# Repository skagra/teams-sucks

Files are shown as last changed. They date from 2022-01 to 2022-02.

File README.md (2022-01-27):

# Teams Sucks

I often find myself on mute during *M$ Teams* meetings and struggle to find the relevant window to be able to unmute.

This project solves the problem by providing an external physical device with buttons to bring *Teams* windows to the front/cycle them, to toggle mute and to toggle the camera.

The project consists of:

* Hardware
   * Based around a Microcontroller, with status LCD and sound signals.   
   * Connectivity to the PC running *Teams* via Bluetooth or USB.
   * Powerable via a battery or USB.
   * C++ software uploaded to the Microcontroller to control the function of the device and to communicate with the PC.
* Protocol
   * A simple network protocol between the hardware device and the PC.
* PC software
   * A .Net application which communicates with the hardware device, taking instructions and driving *Teams* appropriately.

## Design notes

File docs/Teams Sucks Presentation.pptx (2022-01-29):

## YOU’RE

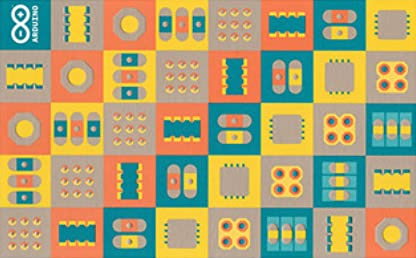
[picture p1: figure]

ON MUTE!

A Device to Control M$ Teams

## Components of the Solution

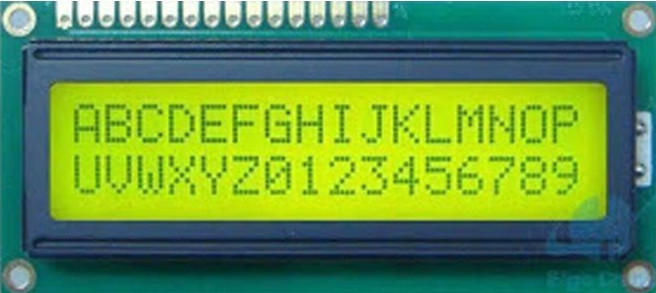
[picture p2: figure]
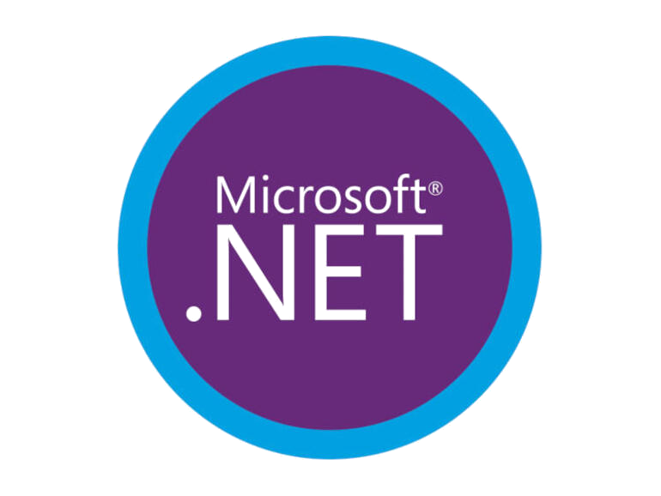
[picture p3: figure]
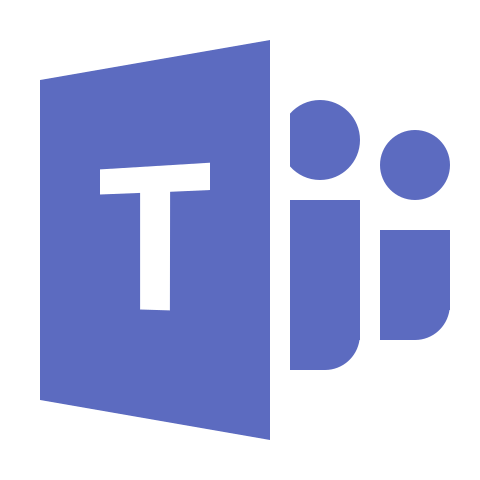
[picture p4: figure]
Microsoft Teams (int. sub-page) | Wired Relations ...

101010010101

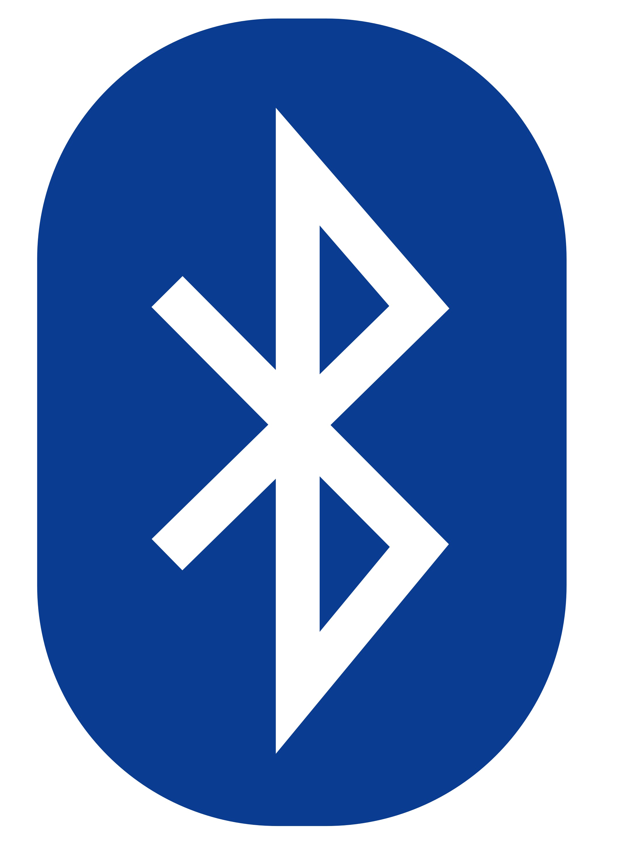
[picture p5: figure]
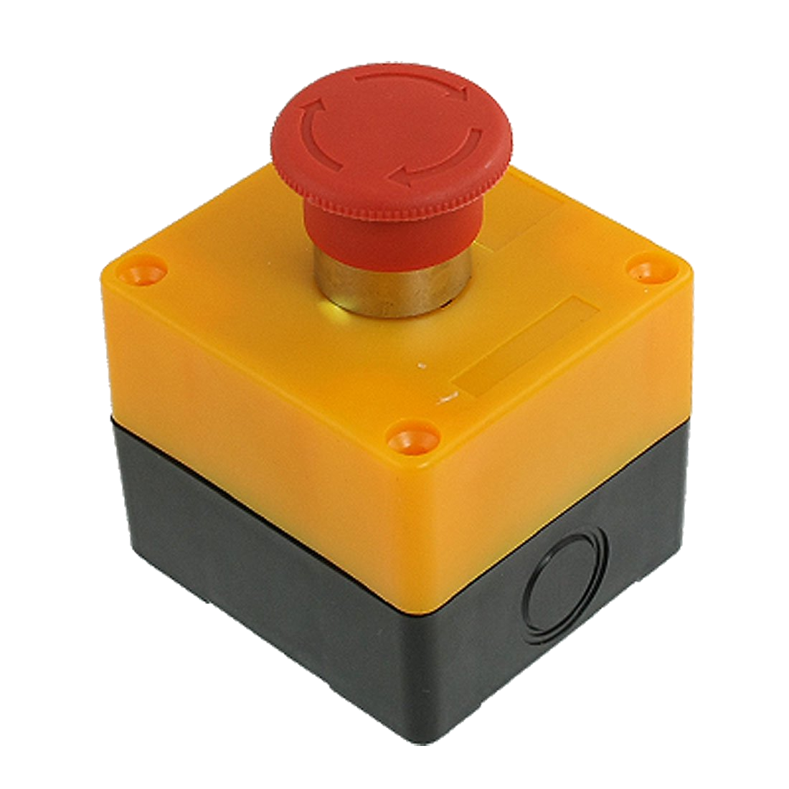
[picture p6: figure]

Cycle
Windows

Toggle
Mute

Toggle
Camera

External

Wireless

PC software to

hardware

protocol

control teams

## Hardware - Microcontroller

C++

Arduino Nano

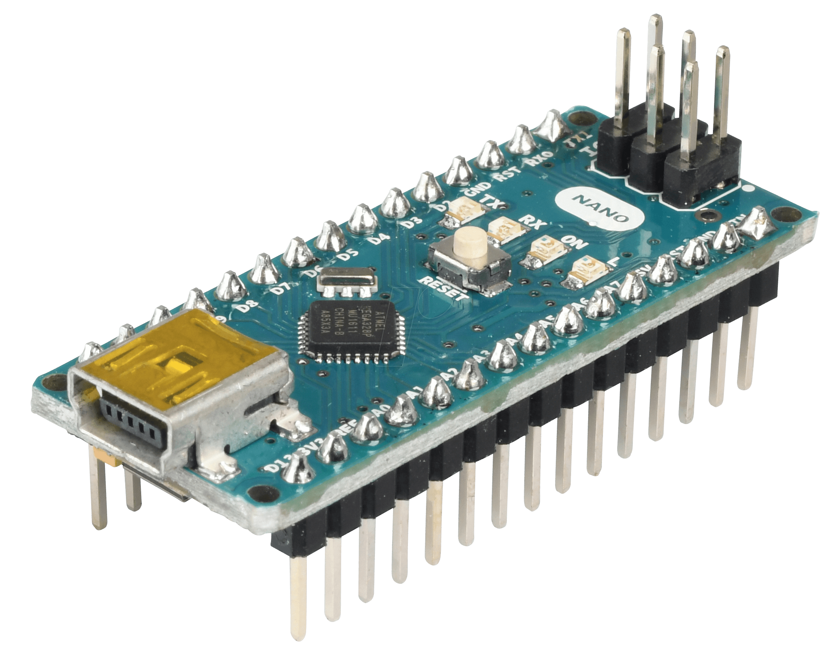
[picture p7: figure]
ARDUINO NANO: Arduino Nano V3, ATmega 328, Mini USB at ...

- ATmega328 Microcontroller
- 32K Flash
- 2K DRAM
- 14 digital I/O pins
- 8 Analogue I/O pins
- 40 mA per pin

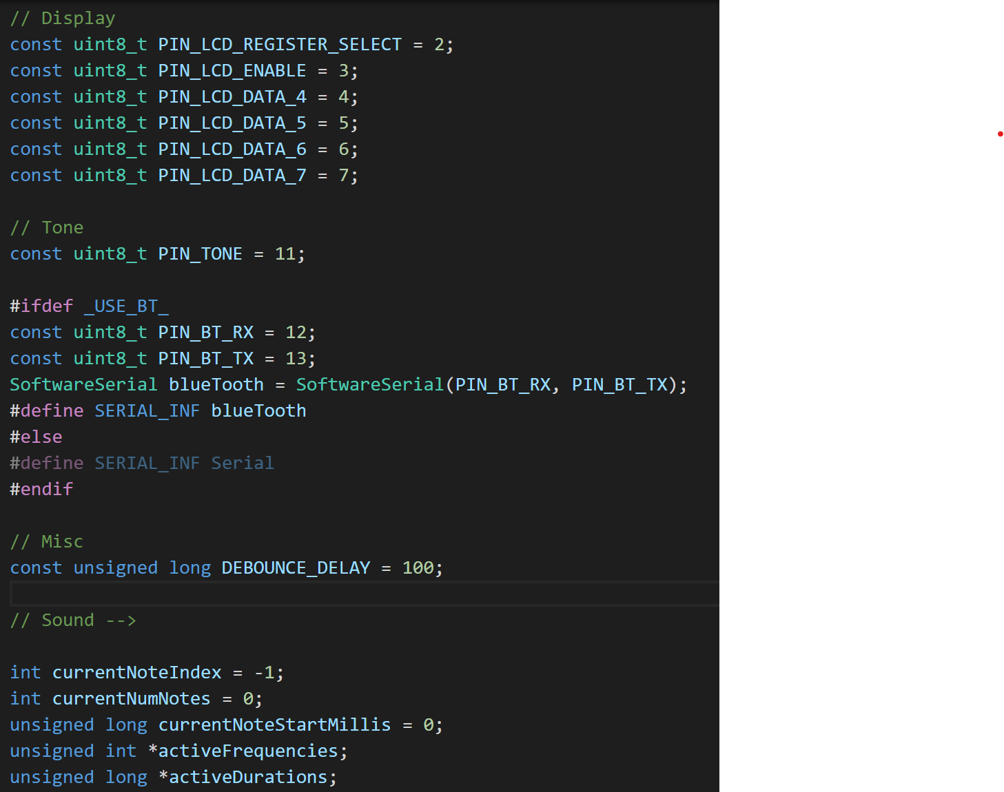
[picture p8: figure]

Compile

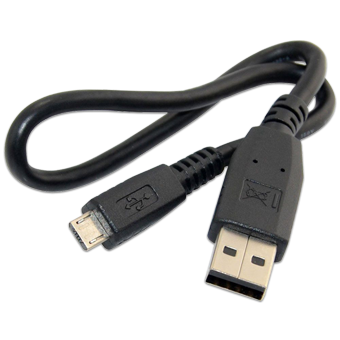
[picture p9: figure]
30cm Short Genuine BlackBerry Micro USB Data Sync Charger ...

Upload

## Hardware - Schematic

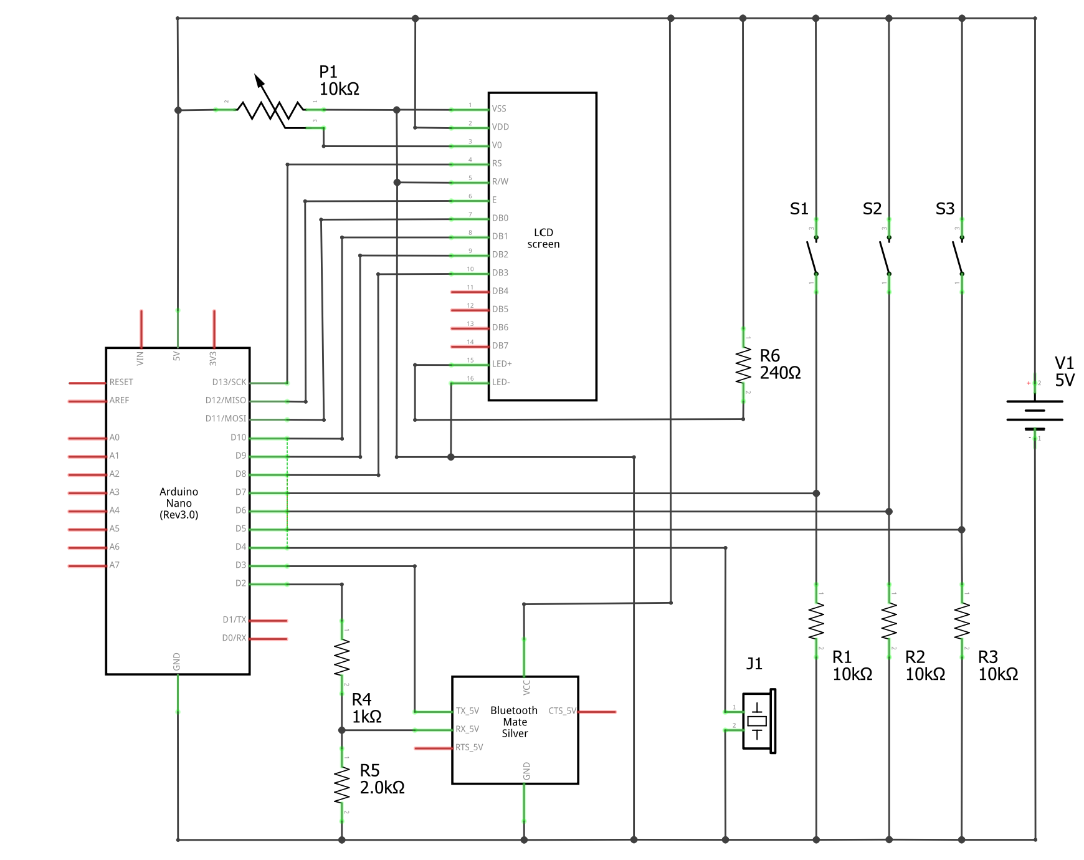
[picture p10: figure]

P1 – LCD contrast

LCD

S1 – Cycle
S2 – Mute
S3 - Camera

R6 - Current limiting resistor for LED backlight

Arduino Nano

Bluetooth/ HC-05

R1, R2, R3 - Pulldown resistors

J1 – Piezo buzzer

R4, R5 - Voltage divider

## Hardware - Reality

## Protocol

## PC Software

## Tracing an Example

## Demo

## Bill of Materials

Wired/USB

Wireless/Bluetooth

Component | # | Total Cost
HC-50 | 1

Component | # | Total Cost
Arduino Nano | 1
LCD Display | 1
Resistors | 6
Potentiometer | 1
Switch | 3
Piezo Buzzer | 1

Battery Power

Component | # | Total Cost
Buck Converter | 1

## Try Yourself?

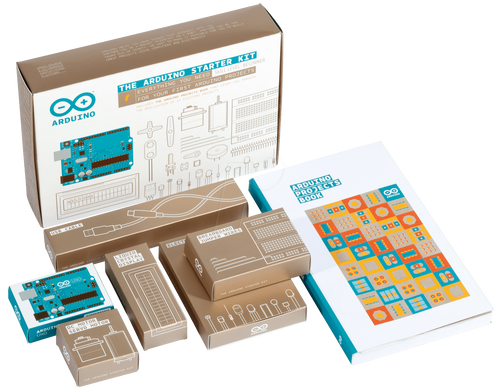
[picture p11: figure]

The

Arduino

Starter

Kit

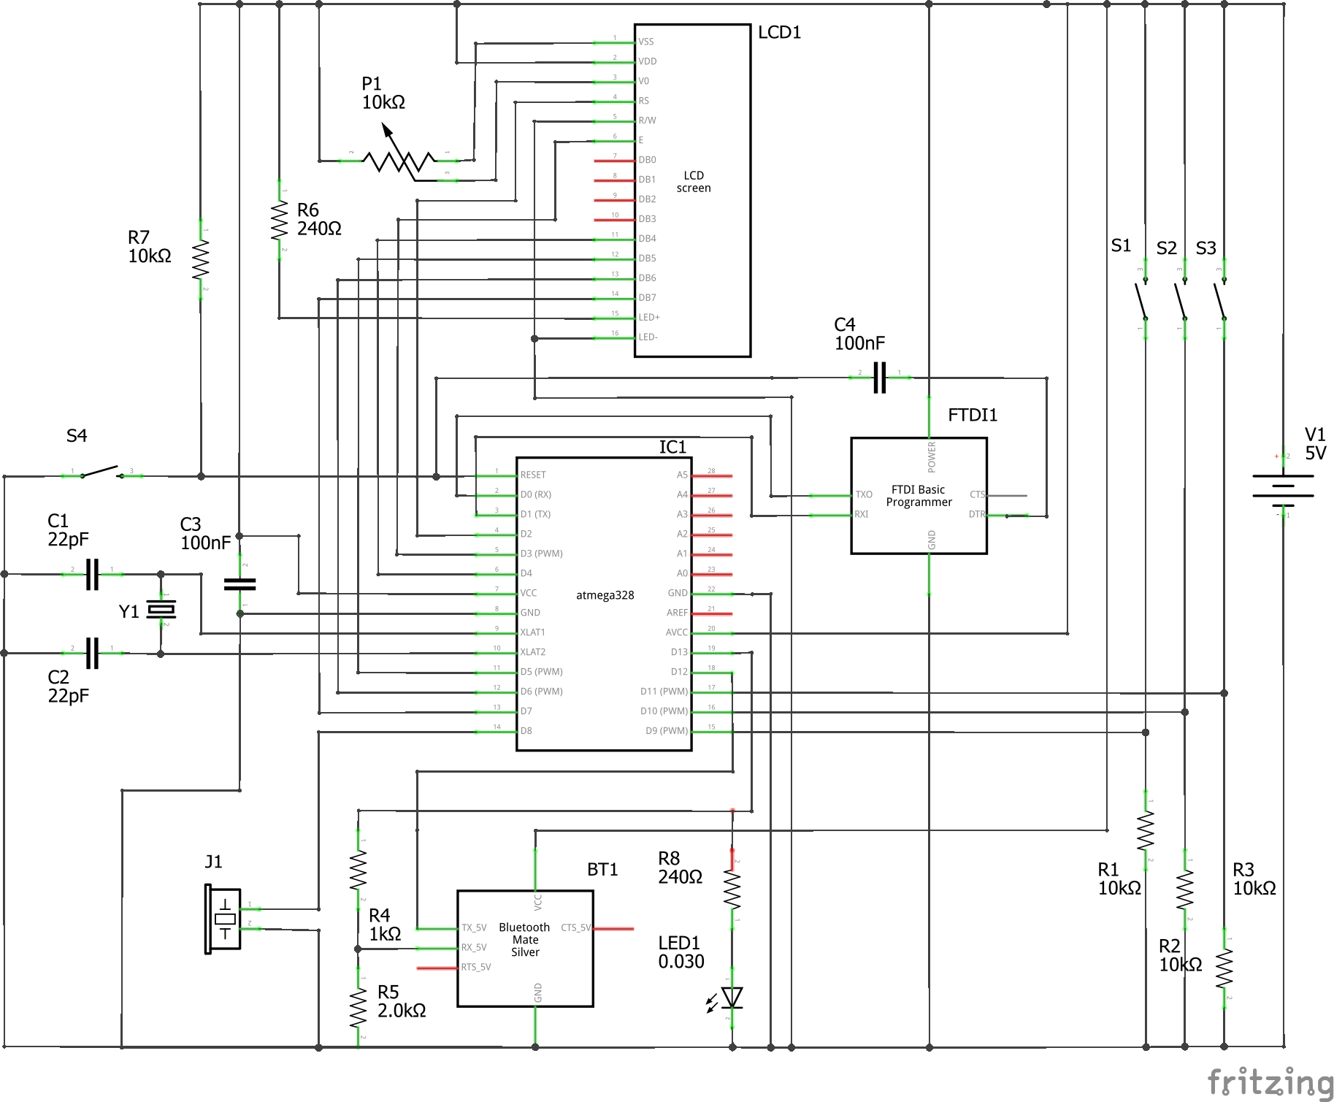
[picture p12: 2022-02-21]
docs/Schematic.png

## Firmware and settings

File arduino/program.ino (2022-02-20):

#include "Player.h"
#include "Button.h"
#include "StatusDisplay.h"
#include "Protocol.h"

using namespace TeamsSucks;

// Pins -->

// Switches
const uint8_t PIN_CYCLE_WINDOWS = 11;
const uint8_t PIN_TOGGLE_MUTE = 9;
const uint8_t PIN_TOGGLE_CAMERA = 10;

// Display
const uint8_t PIN_LCD_REGISTER_SELECT = 2;
const uint8_t PIN_LCD_ENABLE = 3;
const uint8_t PIN_LCD_DATA_4 = 4;
const uint8_t PIN_LCD_DATA_5 = 5;
const uint8_t PIN_LCD_DATA_6 = 6;
const uint8_t PIN_LCD_DATA_7 = 7;

// Tone
const uint8_t PIN_TONE = 8;

// Bluetooth
#ifdef _USE_BT_
const uint8_t PIN_BT_RX = 12;
const uint8_t PIN_BT_TX = 13;
#endif

// <-- Pins

// Sounds -->

unsigned int cycleWindowsFrequencies[] = {250, 750, 1250, 750, 250};
unsigned long cycleWindowsDurations[] = {100, 100, 100, 100, 100};

unsigned int toggleMuteFrequencies[] = {250, 750, 1250};
unsigned long toggleMuteDurations[] = {100, 100, 100};

unsigned int toggleCameraFrequencies[] = {1250, 750, 250};
unsigned long toggleCameraDurations[] = {100, 100, 100};

unsigned int errorFrequencies[] = {250, 100};
unsigned long errorDurations[] = {500, 500};

unsigned int bootFrequencies[] = {250, 500, 750, 1250, 1500};
unsigned long bootDurations[] = {100, 100, 100, 100, 100};

// <-- Sounds

// Help messages
const char *helpMessages[] = {"Teams Sucks", "1 => Cycle Wins", "2 => Toggle Mute", "3 => Toggle Cam"};

// Tune
Player *player;

// Status display
StatusDisplay *statusDisplay;

// Protocol
Protocol *protocol;

// Buttons
Button *cycleWindowsButton;
Button *toggleMuteButton;
Button *toggleCameraButton;

// Button press callbacks
void CycleWindowsCallback(void *clientData)
{
   protocol->sendCycleWindows();
   statusDisplay->setStatusMessage("Cycle windows");
   player->play(cycleWindowsFrequencies, cycleWindowsDurations, sizeof(cycleWindowsFrequencies) / sizeof(unsigned int));
}

void toggleMuteCallback(void *clientData)
{
   protocol->sendToggleMute();
   statusDisplay->setStatusMessage("Toggle mute");
   player->play(toggleMuteFrequencies, toggleMuteDurations, sizeof(toggleMuteFrequencies) / sizeof(unsigned int));
}

void toggleCameraCallback(void *clientData)
{
   protocol->sendToggleCamera();
   statusDisplay->setStatusMessage("Toggle camera");
   player->play(toggleCameraFrequencies, toggleCameraDurations, sizeof(toggleCameraFrequencies) / sizeof(unsigned int));
}

// Protocol callbacks
void errorCallback(void *clientData)
{
   player->play(errorFrequencies, errorDurations, sizeof(errorFrequencies) / sizeof(unsigned int));
}

void setup()
{
   player = new Player(PIN_TONE);

   statusDisplay = new StatusDisplay(helpMessages, sizeof(helpMessages) / sizeof(char *),
                                     PIN_LCD_REGISTER_SELECT, PIN_LCD_ENABLE,
                                     PIN_LCD_DATA_4, PIN_LCD_DATA_5, PIN_LCD_DATA_6, PIN_LCD_DATA_7);

   protocol = new Protocol(errorCallback, (void *)0
#ifdef _USE_BT_
      , PIN_BT_RX, PIN_BT_TX
#endif
   );

   cycleWindowsButton = new Button(PIN_CYCLE_WINDOWS, CycleWindowsCallback, (void *)0);
   toggleMuteButton = new Button(PIN_TOGGLE_MUTE, toggleMuteCallback, (void *)0);
   toggleCameraButton = new Button(PIN_TOGGLE_CAMERA, toggleCameraCallback, (void *)0);

   player->play(bootFrequencies, bootDurations, sizeof(bootFrequencies) / sizeof(unsigned int));

#ifdef _USE_BT_
   statusDisplay->setStatusMessage("Using Bluetooth");
#else
   statusDisplay->setStatusMessage("Using USB");
#endif
}

void loop()
{
   statusDisplay->tick();
   player->tick();

   cycleWindowsButton->tick();
   toggleMuteButton->tick();
   toggleCameraButton->tick();

   protocol->tick();
}

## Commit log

2022-01-22 Added ability to search for com port arduino in on
2022-01-27 Doc edits and added powerpoint
2022-01-27 Added starting point for schematic
2022-01-28 Added working schematic
    [Schematic.fzz]
2022-01-28 Updated schematic and presentation
    [Schematic.fzz]
2022-02-14 Bugged for BT - moving machines
    [program.ino]
2022-02-14 Fixed case of program.ino
2022-02-20 Updated schematic - needs to be checked for errors
    [Schematic.fzz]
2022-02-21 Updated schematic
    [Schematic.fzz]
2022-02-25 Updated schematic and presenation
    [Schematic.fzz]
